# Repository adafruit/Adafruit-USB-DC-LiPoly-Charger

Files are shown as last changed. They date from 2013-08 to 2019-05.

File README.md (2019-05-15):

# PCB for the Adafruit USB/DC Lithium Ion/Polymer charger

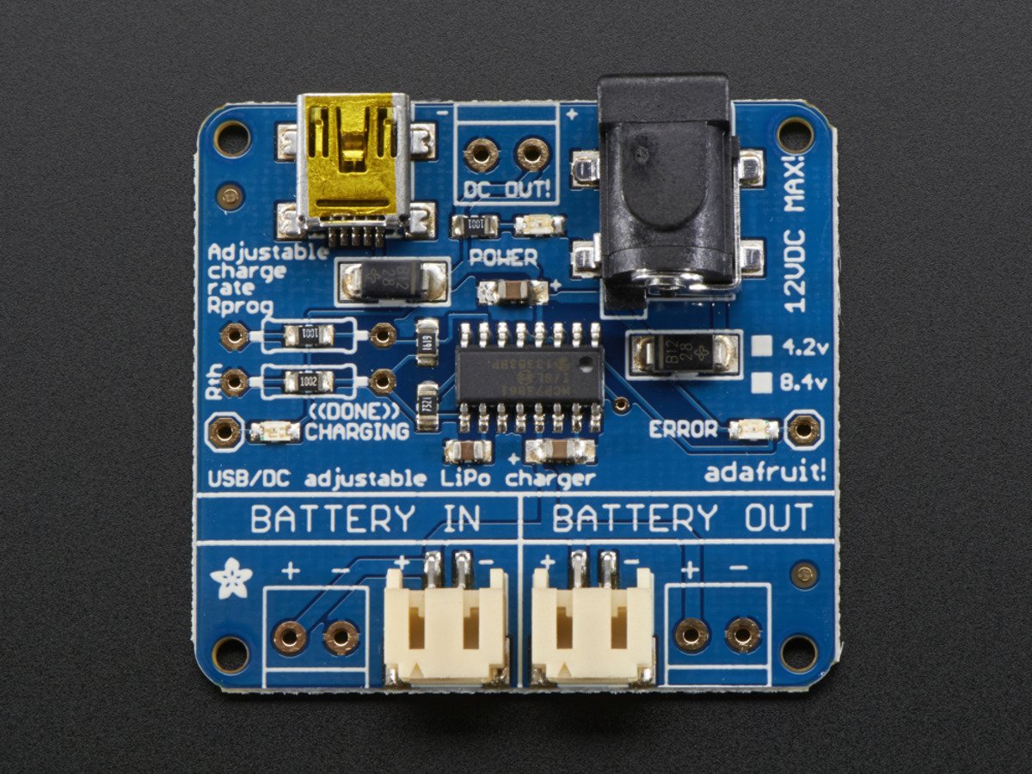
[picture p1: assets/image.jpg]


This is the PCB for the Adafruit USB/DC Lithium Ion/Polymer charger
__Format is EagleCAD schematic and board layout__

Charge your single-cell lithium ion/polymer battery any which way you like with this board. Have a USB connection? No problem, just plug into the miniUSB connector. Only have a wall adapter? Any standard 2.1mm DC adapter which puts out 5 to 12VDC will work fine. If both are plugged in, the charger will automatically choose whichever has the highest voltage.

Other nice things about this charger include multiple LEDs for power & charging status, including a charging LED which will blink when the battery is full. If the charger gets too hot from high-speed charging, it will slow down the charge rate automatically. You can easily adjust the charge rate up to 1.2A or down to 100mA.

For use with Adafruit Lipoly/LiIon batteries only! Other batteries may have different voltage, chemistry, polarity or pinout.

- Use USB or DC power - 5 to 12V input
- Charges one single-cell 3.7/4.2v batteries (not for older 3.6/4.1v cells) with constant current/constant voltage
- Three indicator LEDs - green for Power, orange for charging and red for error
- Charging LED will blink when the battery is full
- You don't have to worry about heat dissipation in the charger, even when plugging in a 12V DC power jack - thermal protection inside will slow down the charge rate to prevent damage
- 2 JST connections so you can keep the battery plugged in and powering your project
- Terminal block connections galore (if you don't like JST connectors) just solder in 3.5mm terminal blocks
- Default charge rate is about 500mA, but you can easily change this by soldering in a through-hole resistor on. The chip can do 100-1200 mA charging
- Safety timer will stop charging after about 14 hours
- The chip supports a standard 10K thermistor, which we have stuffed as a standard resistor. You can solder in a thermistor easily
- [Lots of information in the datasheet for the MCP73861](http://www.microchip.com/wwwproducts/Devices.aspx?dDocName=en020210)
- Fully assembled, tested and comes with a free JST cable
- [Schematic available for your perusal](https://www.adafruit.com/datasheets/mcp73861.png)
- Dimensions: 1.75" x 1.6"

## License

Adafruit invests time and resources providing this open source design, 
please support Adafruit and open-source hardware by purchasing 
products from Adafruit!

Designed by Adafruit Industries.  
Creative Commons Attribution, Share-Alike license, check license.txt for more information
All text above must be included in any redistribution

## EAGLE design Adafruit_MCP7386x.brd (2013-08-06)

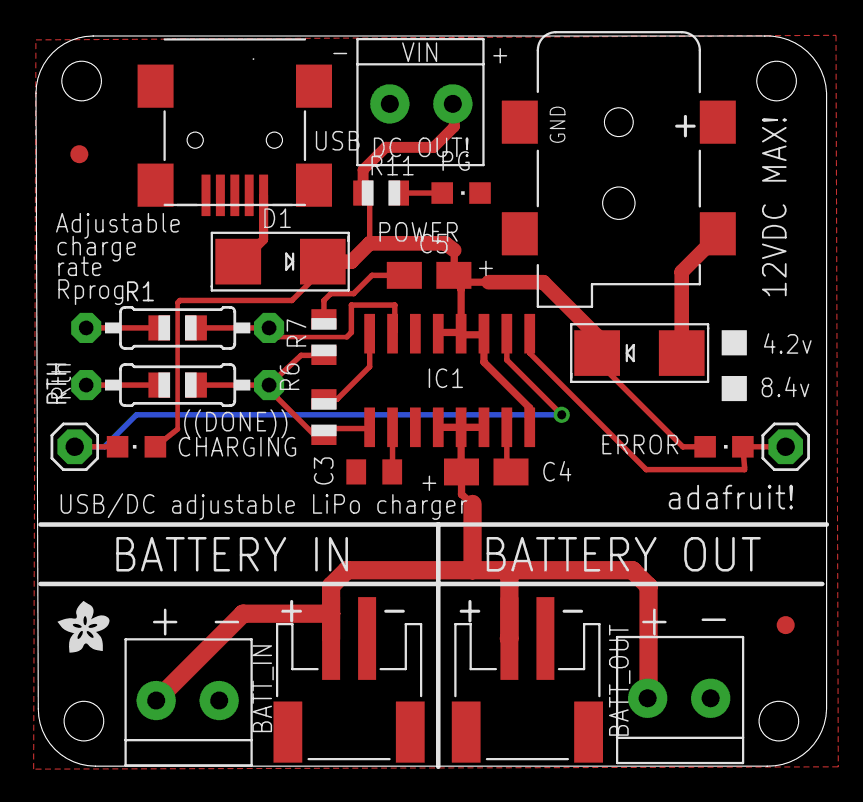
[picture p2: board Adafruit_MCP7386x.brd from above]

Board: 2 copper layers, 43.9 x 40.6 mm, 26 parts (0 on the bottom side), 12 nets.

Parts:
BATT_IN: JSTPH2
BATT_OUT: JSTPH2
C3: 0.47uF; C0805K
C4, C5: 10uF; A/3216-18R
CHG: ORANGE; CHIPLED_0805
D1, D2: B120; SMADIODE
ERR: RED; CHIPLED_0805
IC1: SO16
IN: 1X2-3.5MM; 3.5MMTERM
OUT: 1X2-3.5MM; 3.5MMTERM
PG: GREEN; CHIPLED_0805
R1: adj; 0805-THM
R6: 6.19K; R0805
R7: 7.3k; R0805
R11: 470; R0805
RTH: 10K @ 25degC; 0805-THM
STAT3, STAT4: 1X01
U$1: 2.1MMJACKSMT; DCJACK_2MM_SMT
U$2: ADAFRUIT200MIL
U$3, U$4: FIDUCIAL; FIDUCIAL_1MM
USB: MINI-USB; USB-MINIB
VIN: 1X2-3.5MM; 3.5MMTERM

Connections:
BATT+: BATT_IN.2, BATT_OUT.2, C4.+, IC1.12, IC1.13, IC1.14, IN.2, OUT.2
GND: BATT_IN.1, BATT_OUT.1, C3.2, C4.-, C5.-, IC1.6, IC1.11, IC1.15, IN.1, OUT.1, PG.C, R1.1, R7.2, RTH.1, U$1.GND, U$1.GNDBREAK, USB.GND, VIN.1
unnamed: D1.A, USB.VBUS
unnamed: IC1.7, R1.2
unnamed: CHG.C, IC1.2, STAT3.1
unnamed: ERR.C, IC1.1, STAT4.1
unnamed: C3.1, IC1.10
unnamed: IC1.8, R6.2
unnamed: IC1.9, R6.1, R7.1, RTH.2
unnamed: PG.A, R11.2
unnamed: D2.A, U$1.PWR2
VCC: C5.+, CHG.A, D1.C, D2.C, ERR.A, IC1.3, IC1.4, IC1.5, IC1.16, R11.1, VIN.2

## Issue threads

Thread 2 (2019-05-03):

typo in readme

ladyada, 2019-05-03:
_This is the PCB for the Adafruit 1.5" Color OLED display breakout board Format is EagleCAD schematic and board layout_
@hoffmannjan

hoffmannjan, 2019-05-15:
https://github.com/adafruit/Adafruit-USB-DC-LiPoly-Charger/pull/3

Closed 2019-05-15.
